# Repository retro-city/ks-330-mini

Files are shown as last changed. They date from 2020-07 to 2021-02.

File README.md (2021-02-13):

# KS-330 Mini

This project aims to provide CAD drawings and material to a faithful reproduction of one of the most iconic computer
cases from the early 1990s, the [MACASE DIAMOND
KS-330](https://web.archive.org/web/19980502082047/http://macase.com/product/personal/ks-330.htm). Ultimately the goal is to provide a set of suitable 3D Printed models to create a general purpose
miniature sized KS-330 case for a Raspberry Pi,
[MiSTer](https://github.com/MiSTer-devel/Main_MiSTer/wiki) and similar systems which will provide
compatibility with MS-DOS retro games.

Models are reproduction based on measures from an original case. The focus is primarily on visual
details. Areas which are not visible or clearly a result from practicality around the original
injection molds might not be accurately reproduced.

Please report any suggestions or issues using the GitHub issue tracker.<br />
Interested in purchasing ready-to-use products? Contact <a href="mailto:sales@retrocity.no">sales@retrocity.no</a>.

## List of manufacturers

The following manufacturers have been identified to use the KS-330 or equivalent clones or versions in their
PC production in the early 1990s:

* Executive (unoriginal case) (Italy)
* Cardinal Computer (Cookeville, TN, USA)
* TCi Computer AS (Bergen, Norway)

## Licensing

<br /><br />3D Models, CAD files and renders are licensed under the <a rel="license"
href="http://creativecommons.org/licenses/by-nc-sa/4.0/">Creative Commons
Attribution-NonCommercial-ShareAlike 4.0 International License</a>.
<br/><br/>
<a rel="license" href="https://www.gnu.org/licenses/gpl-3.0.en.html">GNU GPLv3 License</a><br />
All original programs and scripts related to this project are licensed under the <a rel="license" href="https://www.gnu.org/licenses/gpl-3.0.en.html">GNU General Public License v3</a> unless otherwise is specifically stated. 3rd party software, utilities and libaries are subject to their respective licenses.

## Components

### KS-330 Mini

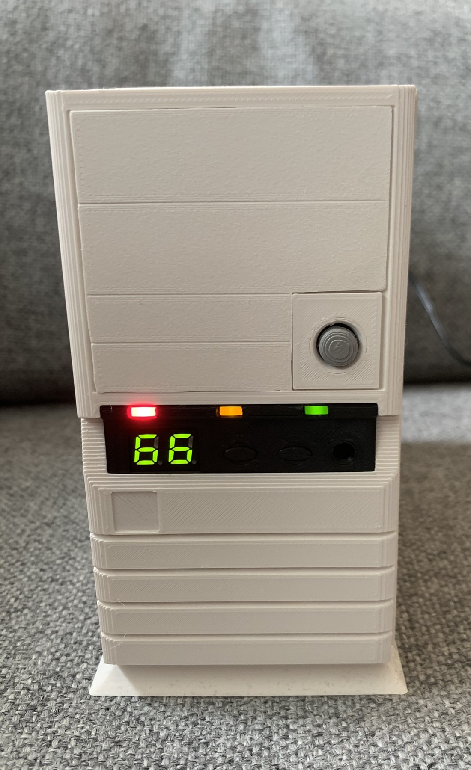
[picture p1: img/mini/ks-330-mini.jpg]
 This folder contains models speficially  adjusted for a 1:2.5 (40%) size reduction which
makes the case comparable in size to the commercially released Mini and Classic consoles. Currently there
exists a case frame with support for Rasbperry Pi SoC motherboards. Other versions are planned in
the future.

The model uses M2.5 screws in a mix of 6mm and 8mm lengths. Some holes are threaded, but should
be secured with washers and nuts where possible.

**Note!** As of `beta3` we have an increased focus on keeping the parts bacwards compatible. It is
now possible to recreate a complete case with great looks and authenticity. The IO panel is still
work in progress. General fitment/assembly will be improved in future revisions.
<br clear="right"/>
<br />

#### Front Panel

| Front | Drive-Bay-Plain | Power-Button
|---|---|---|
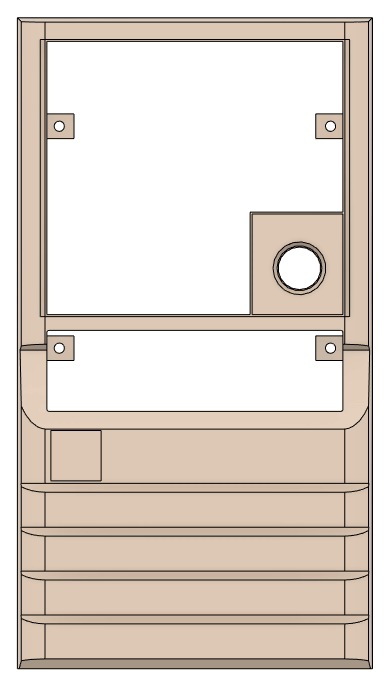
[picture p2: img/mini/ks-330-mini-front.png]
KS-330 Front
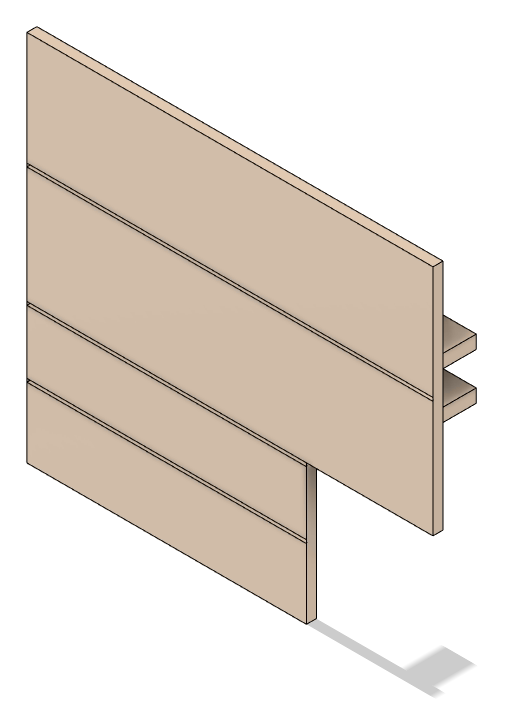
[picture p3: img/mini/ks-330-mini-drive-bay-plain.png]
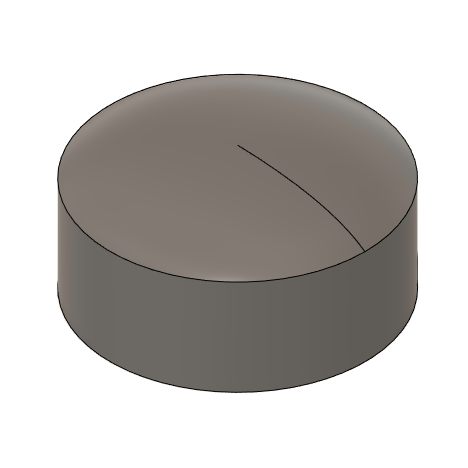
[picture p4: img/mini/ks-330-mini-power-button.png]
|   |   |   |

Front panel with hole for push button ([Judco
40-4526-00](https://www.digikey.no/product-detail/no/judco-manufacturing-inc/40-4526-00/545PB-ND/1277805))
and

**Progress:** Completed in beta3. Future revision will focus on better/more durable screw hole
positioning. Possible adjustments to IO-Panel area. More drive bay inserts will be added in the future.

#### Frame

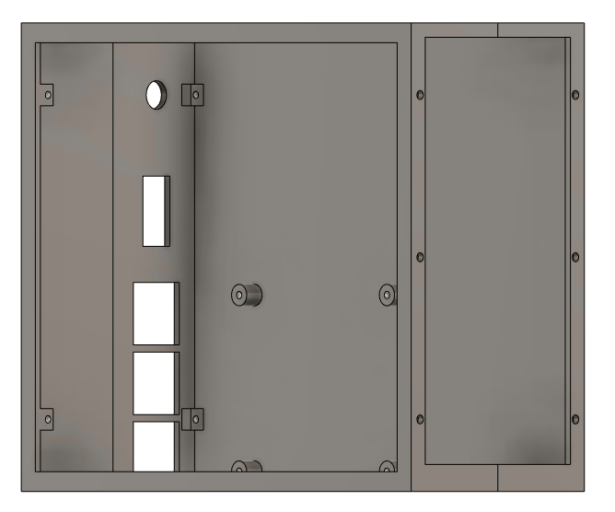
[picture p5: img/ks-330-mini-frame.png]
KS-330 Mini Frame


The inner `frame` of the case. Split into two different STLs to improve 3D printability. Screw holes
in front is intended to fasten the front panel as well as future drive bay accessory and fan
assemblies. There are screw holes in the back to fasten the `sleeve` and holes in bottom to fasten
the `base plate`. The right and the left parts can optionally be glued together.

**Progress:** Completed in beta3. Future revisions will focus on case fitment and
screw hole. Looking into using some kind of panel mount standard for IO holes.

#### Outer Sleeve

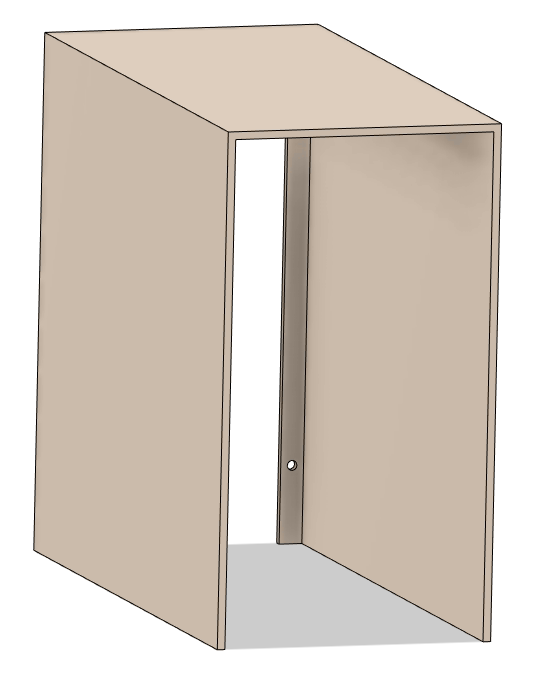
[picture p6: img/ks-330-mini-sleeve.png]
KS-330 Mini Sleeve


The outer `sleeve` is intended to go on top of the inner `frame` and align with the front panel, just as the
original case.

**Progress:** Completed in beta3. Edges on top has to be rounded in future revision.

#### IO Panel

| IO-Panel | IO-Panel-Button
|---|---|
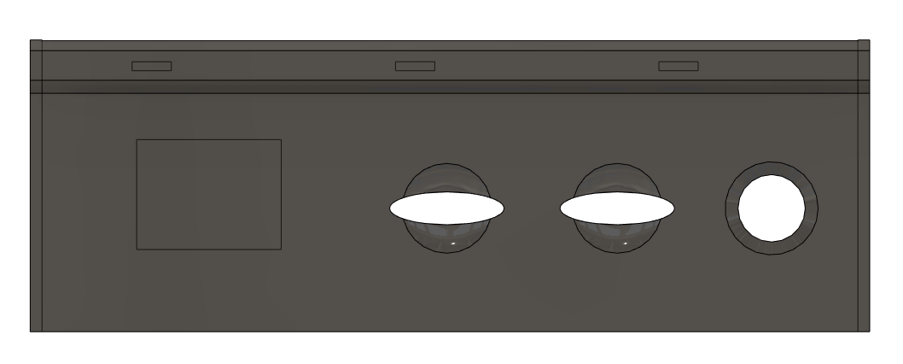
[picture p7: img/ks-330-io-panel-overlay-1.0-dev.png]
KS-330 IO Panel
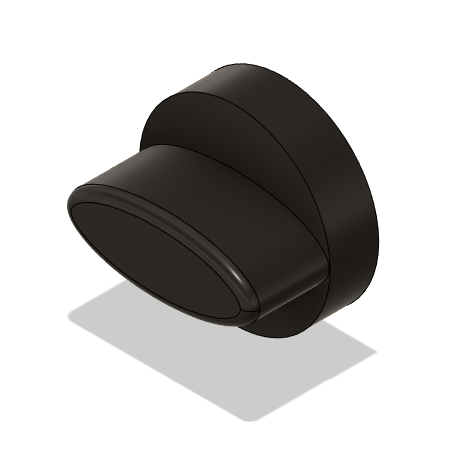
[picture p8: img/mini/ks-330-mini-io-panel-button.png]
KS-330 IO Panel
|  |  |

Customized version of the IO Panel.

LED holes are completly open to account for non-transparent
material and widened to support 2mmx5mm square LEDs. The original case uses red for HDD, yellow for
Turbo and green for Power.

The Clock Speed indicator is altered to fit [0.28" 2-digit 7-segment
displays](https://lcsc.com/product-detail/Led-Segment-Display_SUNLIGHT-SLR0282BH2C1BD-6-6_C225881.html). The
`common cathode` versions are the best as these work better with LED drivers. Green is the color
versions that closest matches the original. Our choice of LED driver fell on
MAX7219CWG+T due to a good combination of price, availability and ease of use. A poor man's option
is to just hard wire the LEDs. But then you're stuck with two identical numbers

**Progress:** Completed in beta3.

#### IO Panel PCB

| IO-Panel-PCB | | IO-Panel-PCB (early prototype) | |
|---|-|-|-|
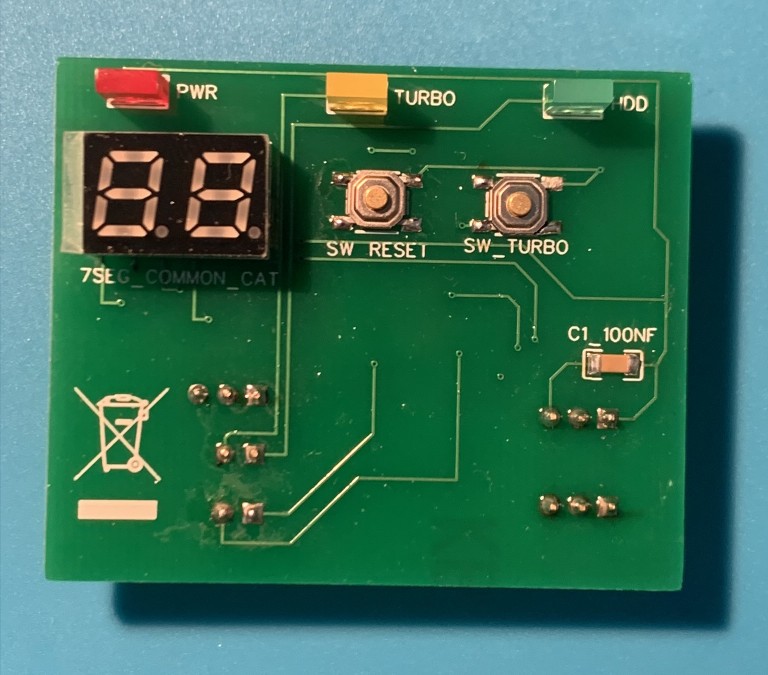
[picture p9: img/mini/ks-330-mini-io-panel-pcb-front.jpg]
KS-330 IO Panel
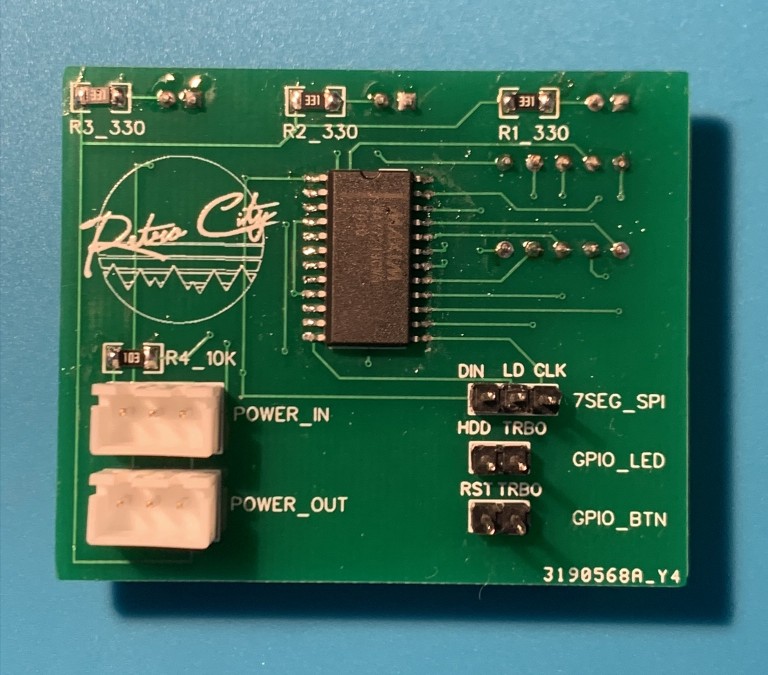
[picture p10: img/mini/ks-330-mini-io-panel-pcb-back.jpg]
KS-330 IO Panel
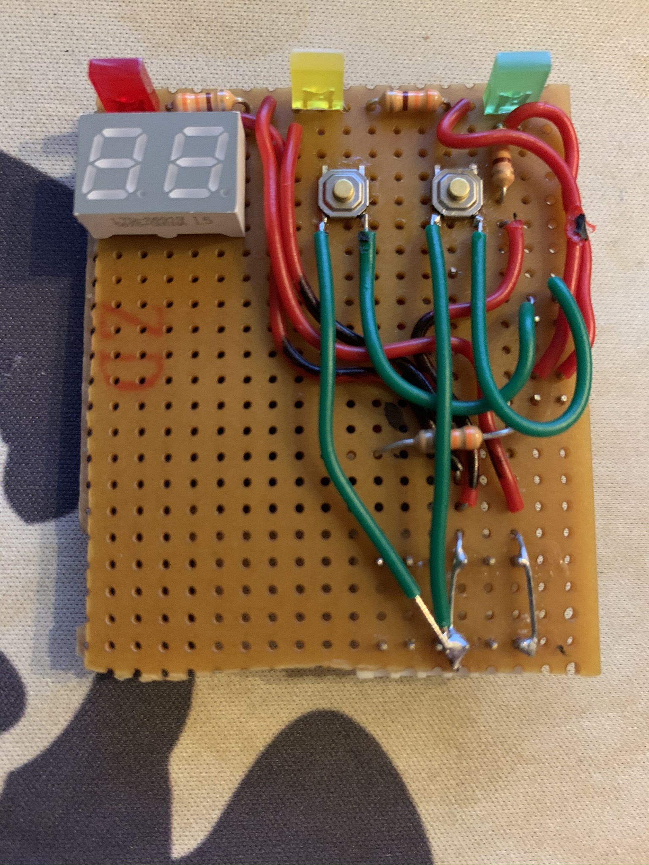
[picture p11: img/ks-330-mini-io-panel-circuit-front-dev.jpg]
KS-330 IO Panel
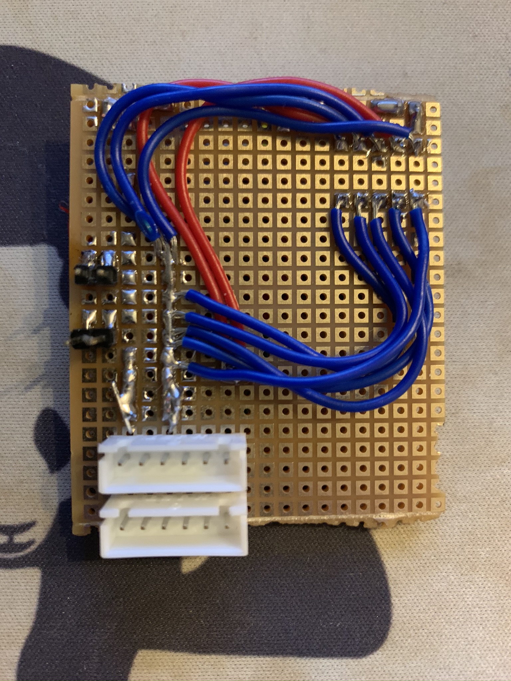
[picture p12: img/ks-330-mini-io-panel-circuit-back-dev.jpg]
KS-330 IO Panel
|  |  |  |  |

Initial revision of the PCB with Power HDD and Turbo LEDs. HDD and Turbo LEDs as well as Reset and
Turbo buttons are controlled via GPIO (buttons are wired from GPIO to Ground for the simplest
possible circuitry). 7SEG is controlled through MAX7219 controller. GPIO uses Mini-PV (Dupont) connectors. JST-XH connectors are used for 5V power in/out. 

**Progress:** Completed in beta3.

### Full Size

The components in the main STL-directory is full size replicas of the original KS-330 case. There
are minor modifications done to improve slicer stability when scaled down.

The following components have been recreated in full size.

| KS-330-Front | Full Progress |
|---|---|
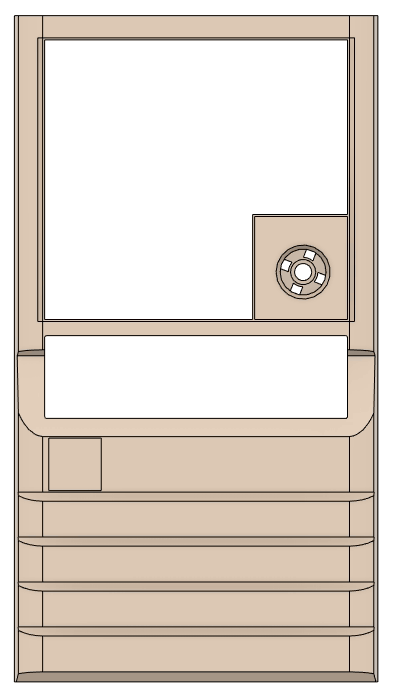
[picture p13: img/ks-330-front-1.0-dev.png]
KS-330 Front
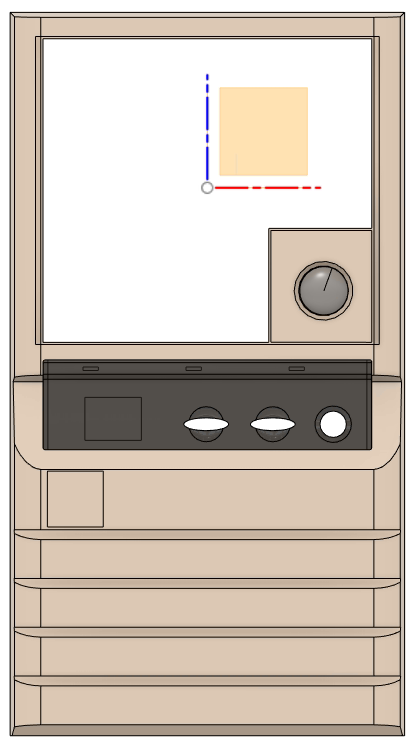
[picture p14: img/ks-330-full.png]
|   |   |

**Progress:** Work in progress, tested in 40% scale. `Front` is pretty accurate, but missing various
screw hole mounts on  the back side. Edges are not rounded.

| KS-330-IO-Panel-Overlay |
|-----------------|
| KS-330 IO Panel Overlay
|

**Progress:** Work in progress, tested in full scale. `IO-Panel-Overlay` is pretty much complete,
but missing holes to clip onto the `IO-Panel`. Edges are not rounded.

| KS-330-Base-Plate |
|-----------------|
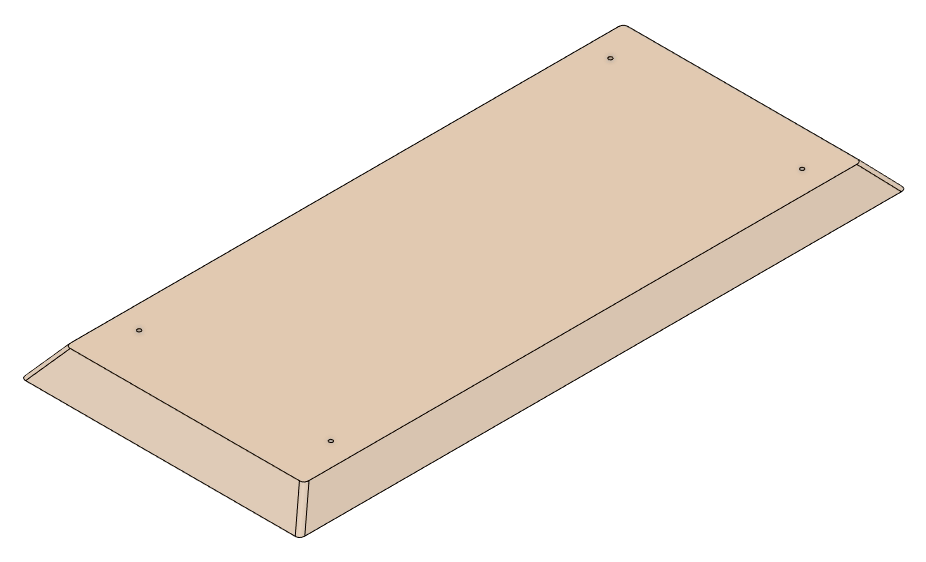
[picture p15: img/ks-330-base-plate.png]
|  |

**Progress:** Completed and tested in 40% scale. Bottom is missing arrow marking to define front.

### Clone

The clone directory contains models based on measurements from a clone system. Quality is low
compared to the original KS-330 cases and models have fitment issues also found persisted in the
original clone parts.

| Clone-Bay-Cover-3.5 | Clone-Bay-Cover-5.25 |
|---|---|
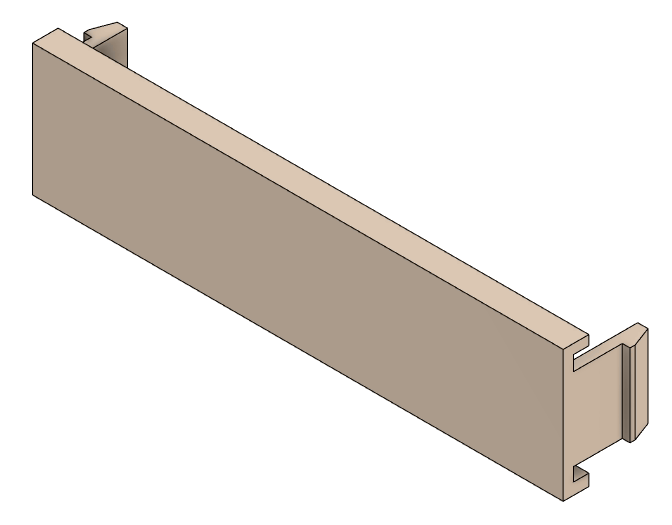
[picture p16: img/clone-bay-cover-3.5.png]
Clone Bay Cover 3.5"
|  | No picture |

Drive Bay Covers for 3.5" and 5.25" bays. Works with `KS-330-Front-Panel`. Fitment of the clone covers are
not 100%, but it is possible to adjust this with a precision knife without degrading quality. 

**Progress:** Completed, tested in full scale. 

| Clone-Power-Button |
|-----------------|
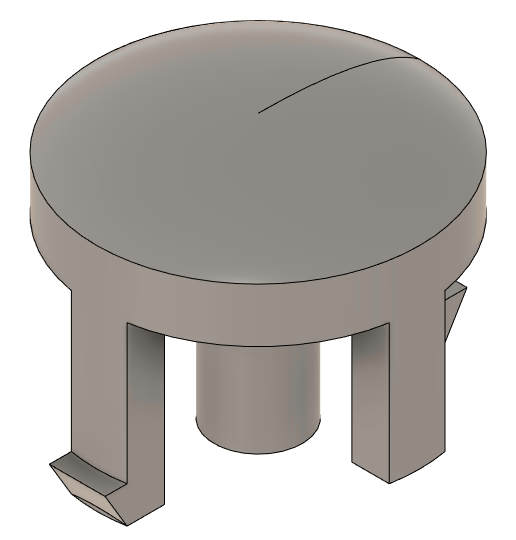
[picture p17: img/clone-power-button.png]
Clone Power Button
|  |

Power Button. Works with `KS-330-Front-Panel` but is not an accurate representation of the original
power button. Requires a low tension compression spring (Outer Ø=8mm, Inner Ø=7mm L=18mm Closed,
Squared and Ground) to work as intended.

**Progress:** Completed, tested in full scale.

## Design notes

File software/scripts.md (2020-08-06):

LED and Button Input/Output:

### Enable HDD LED:
```
sudo nano /boot/config.txt
```

Add the following `dtoverlay`
```
dtoverlay=act-led,gpio=17
```

### Turbo Button and LED:

```python
import RPi.GPIO as GPIO

# Use BCM-style pin referencing
GPIO.setmode(GPIO.BCM)

# Activate Turbo LED
GPIO.setup(27,GPIO.OUT)
GPIO.output(27,GPIO.HIGH)

# Activate Turbo Button
GPIO.setup(23, GPIO.IN, pull_up_down=GPIO.PUD_UP)

# Create a Toggle Function
def toggle_turbo(channel):
    turbo = not GPIO.input(27)
    if (turbo):
            GPIO.output(27, GPIO.HIGH)
    else:
            GPIO.output(27, GPIO.LOW)

# Add Event which runs the toggle function
GPIO.add_event_detect(23, GPIO.RISING, callback=toggle_turbo)
```

## 7 segment

https://datasheets.maximintegrated.com/en/ds/MAX7219-MAX7221.pdf
https://pypi.org/project/spidev/
https://learn.sparkfun.com/tutorials/raspberry-pi-spi-and-i2c-tutorial/all

```
 sudo apt-get install python3-pip

import time, spidev
spi = spidev.SpiDev()
spi.open(0,0)
spi.max_speed_hz = 8000000

spi.xfer2([0x0C, 0x01]) # turn on
spi.xfer2([0x09, 0x00]) # decode mode none
spi.xfer2([0x0B, 0xFF]) # set intensity

spi.xfer2([0x0F, 0x00]) # turn off displaytest
spi.xfer2([0x0F, 0x01]) # turn on displaytest

# 0x30 left digit, 0x40 right digit, 0x60 both

def init():
    spi.xfer2([0x0C, 0x01]) # turn on
    spi.xfer2([0x09, 0x00]) # decode mode none
    spi.xfer2([0x0B, 0xFF]) # set intensity
    spi.xfer2([0x0F, 0x00]) # turn off displaytest

# 66
def d66():
    spi.xfer2([0x01, 0x60])
    spi.xfer2([0x02, 0x00])
    spi.xfer2([0x03, 0x60])
    spi.xfer2([0x04, 0x60])
    spi.xfer2([0x05, 0x60])
    spi.xfer2([0x06, 0x60])
    spi.xfer2([0x07, 0x60])
    spi.xfer2([0x08, 0x00])

# 33
def d33():
    spi.xfer2([0x01, 0xFF])
    spi.xfer2([0x02, 0xFF])
    spi.xfer2([0x03, 0xFF])
    spi.xfer2([0x04, 0xFF])
    spi.xfer2([0x05, 0x00])
    spi.xfer2([0x06, 0x00])
    spi.xfer2([0x07, 0xFF])
    spi.xfer2([0x08, 0x00])

# Blank
def Blank():
    spi.xfer2([0x01, 0x00])
    spi.xfer2([0x02, 0x00])
    spi.xfer2([0x03, 0x00])
    spi.xfer2([0x04, 0x00])
    spi.xfer2([0x05, 0x00])
    spi.xfer2([0x06, 0x00])
    spi.xfer2([0x07, 0x00])
    spi.xfer2([0x08, 0x00])

# Pi
def Pi():
    spi.xfer2([0x01, 0x30])
    spi.xfer2([0x02, 0x30])
    spi.xfer2([0x03, 0x00])
    spi.xfer2([0x04, 0x00])
    spi.xfer2([0x05, 0xFF])
    spi.xfer2([0x06, 0xFF])
    spi.xfer2([0x07, 0x30])
    spi.xfer2([0x08, 0x00])

# Hi
def Hi():
    spi.xfer2([0x01, 0x00])
    spi.xfer2([0x02, 0x30])
    spi.xfer2([0x03, 0x30])
    spi.xfer2([0x04, 0x00])
    spi.xfer2([0x05, 0x60])
    spi.xfer2([0x06, 0x60])
    spi.xfer2([0x07, 0x30])
    spi.xfer2([0x08, 0x00])

# Lo
def Lo():
    spi.xfer2([0x01, 0x00])
    spi.xfer2([0x02, 0x00])
    spi.xfer2([0x03, 0x40])
    spi.xfer2([0x04, 0x60])
    spi.xfer2([0x05, 0x60])
    spi.xfer2([0x06, 0x30])
    spi.xfer2([0x07, 0x40])
    spi.xfer2([0x08, 0x00])

```

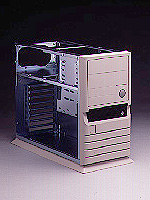
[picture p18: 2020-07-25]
img/ks-330d-i.jpg

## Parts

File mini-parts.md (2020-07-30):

Power Button:

https://www.digikey.no/product-detail/no/judco-manufacturing-inc/40-4526-00/545PB-ND/1277805
https://media.digikey.com/pdf/Data%20Sheets/Judco%20PDFs/40-4526-00.pdf

Power Jack:

https://www.digikey.no/product-detail/no/mpd-memory-protection-devices/EJ501A/EJ501A-ND/2439531

LEDS:

https://www.digikey.no/product-detail/no/kingbright/WP113IDT/754-1201-ND/1747600
https://www.digikey.no/product-detail/no/kingbright/WP113GDT/754-1200-ND/1747599
https://www.digikey.no/product-detail/no/kingbright/WP113YDT/754-1203-ND/1747602

Turbo Switch:

https://www.digikey.no/product-detail/no/e-switch/TL2230EEF100/EG6030-ND/3778181

Reset Switch:

(note: silent, not good enough sound)
https://www.digikey.no/product-detail/no/e-switch/TL2230OAF140/EG6032-ND/4029360

Need to find lower height switches if they are to fit PCB.

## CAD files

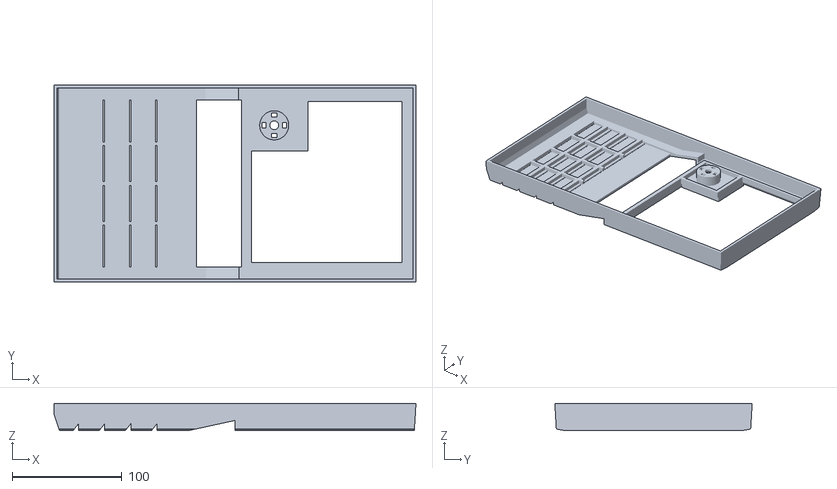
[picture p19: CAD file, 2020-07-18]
stl/clone/front.stl
330.0 x 180.0 x 25.0

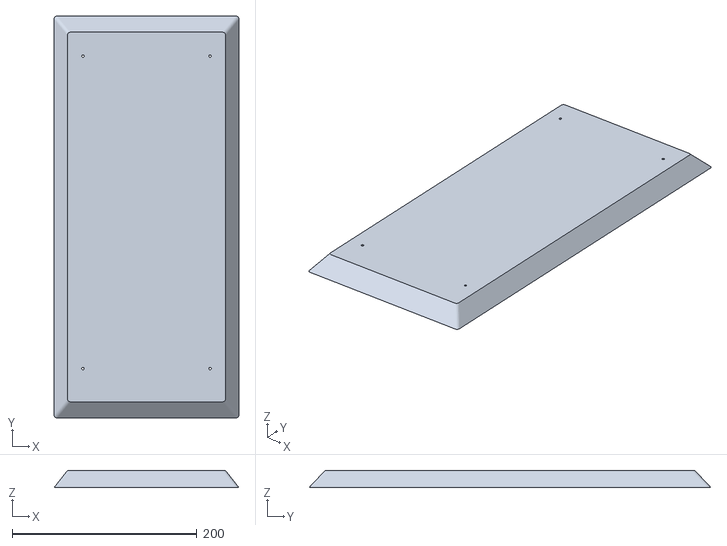
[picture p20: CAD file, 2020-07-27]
stl/full/ks-330-base-plate.stl
200.0 x 435.0 x 18.5

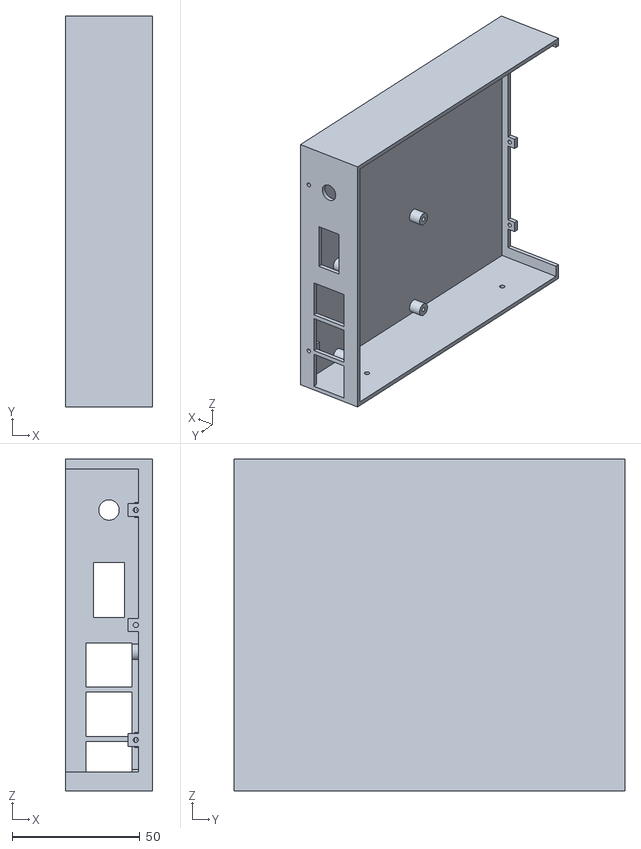
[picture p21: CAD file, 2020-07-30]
stl/mini/1.0-beta2/ks-330-mini-frame-right-rpi-1.0-beta2.stl
34.0 x 153.0 x 130.0

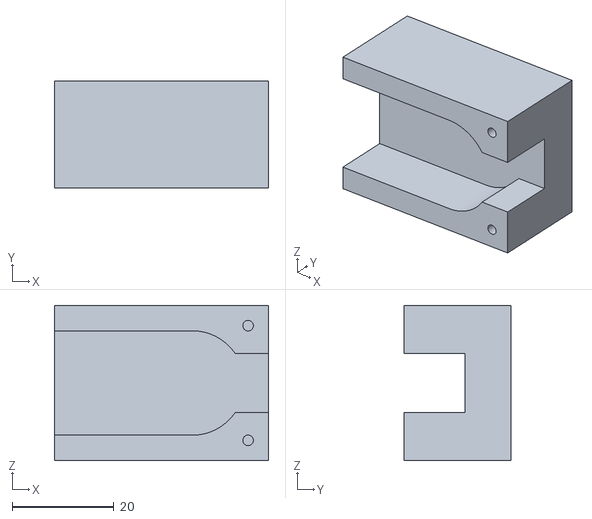
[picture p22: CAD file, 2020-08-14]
stl/mini/1.0-beta3/ks-330-mini-hdmi-mount-1.0-beta3.stl
42.0 x 21.0 x 30.5

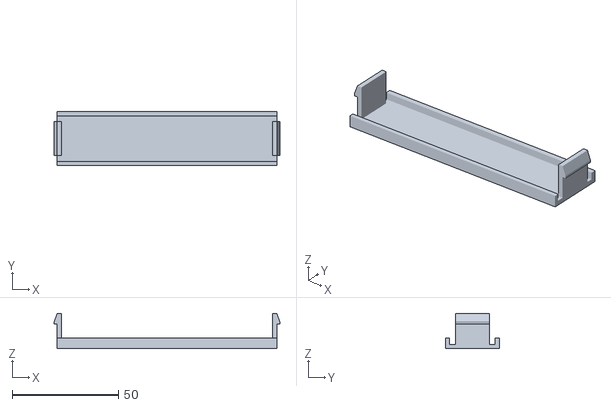
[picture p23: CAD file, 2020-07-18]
stl/clone/cover-3.5.stl
106.2 x 25.6 x 16.5

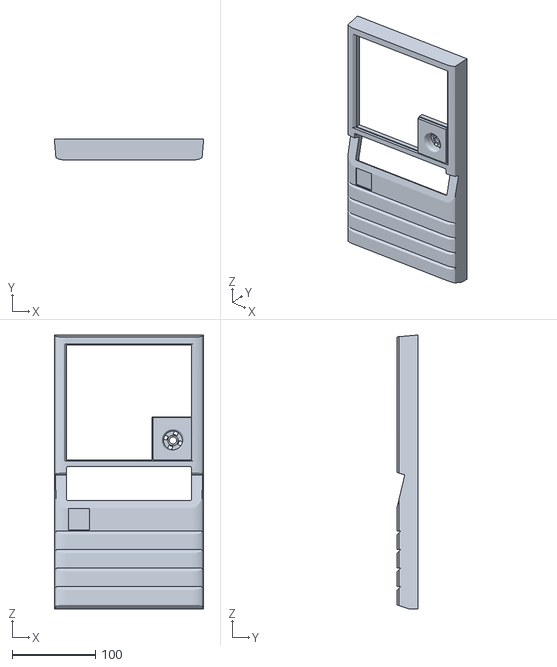
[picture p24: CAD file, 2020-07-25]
stl/full/ks-330-front-1.0-dev3.stl
180.0 x 25.5 x 330.0

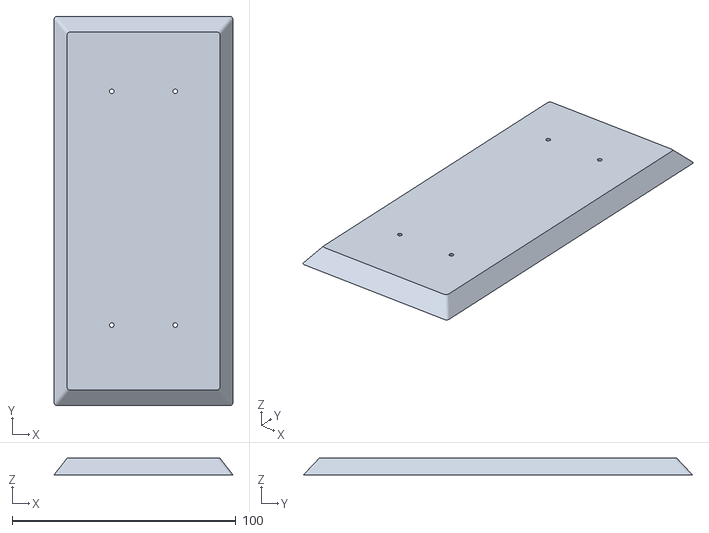
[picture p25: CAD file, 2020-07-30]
stl/mini/1.0-beta2/ks-330-mini-base-plate-1.0-beta2.stl
80.0 x 174.0 x 7.40

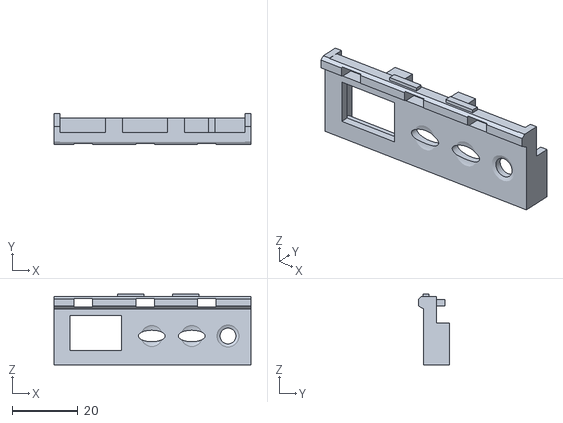
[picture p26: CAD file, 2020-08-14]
stl/mini/1.0-beta3/ks-330-mini-io-panel-1.0-beta3.stl
59.9 x 9.44 x 21.5

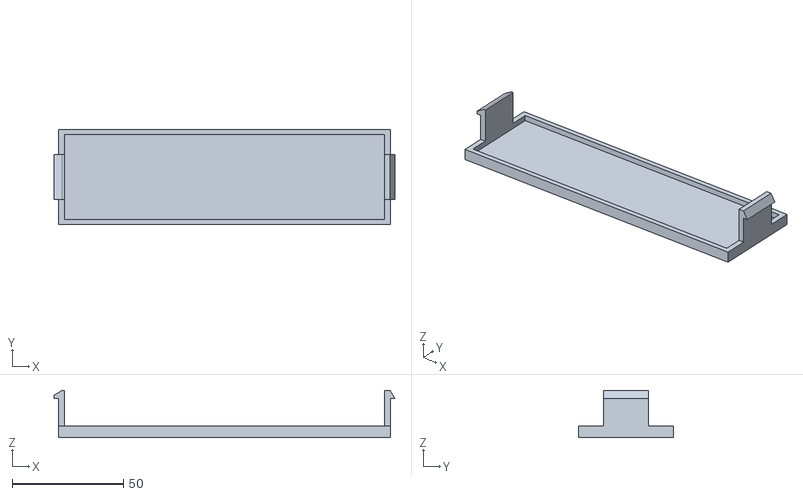
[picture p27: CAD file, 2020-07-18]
stl/clone/cover-5.25.stl
153.1 x 42.8 x 21.2

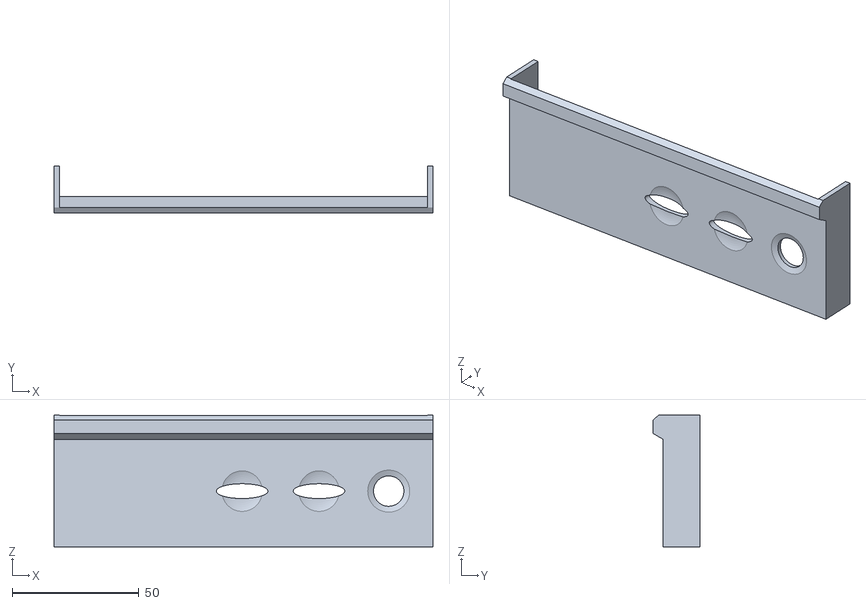
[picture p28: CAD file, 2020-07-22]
stl/full/ks-330-io-panel-overlay-1.0-dev.stl
149.8 x 18.6 x 52.0

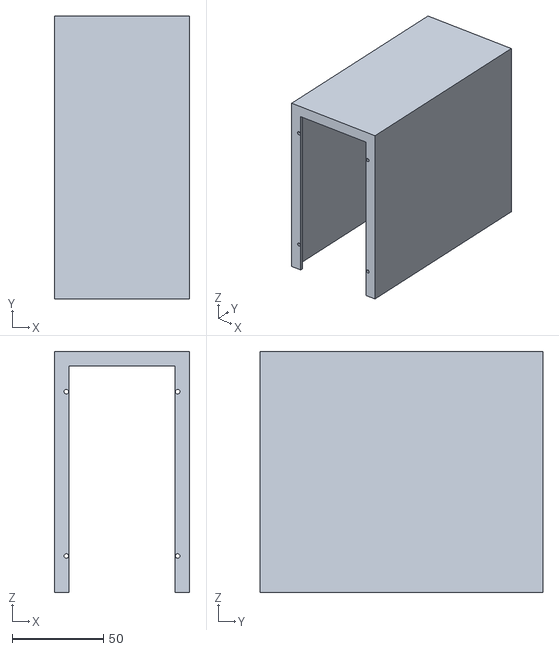
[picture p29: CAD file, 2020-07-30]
stl/mini/1.0-beta2/ks-330-mini-sleeve-1.0-beta2.stl
74.0 x 155.0 x 132.0

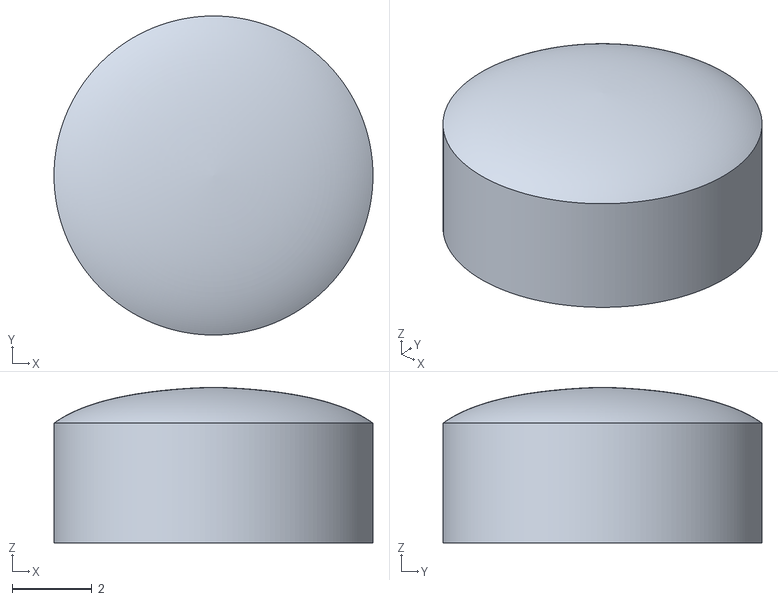
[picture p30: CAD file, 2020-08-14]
stl/mini/1.0-beta3/ks-330-mini-power-button-1.0-beta3.stl
8.00 x 8.00 x 3.90

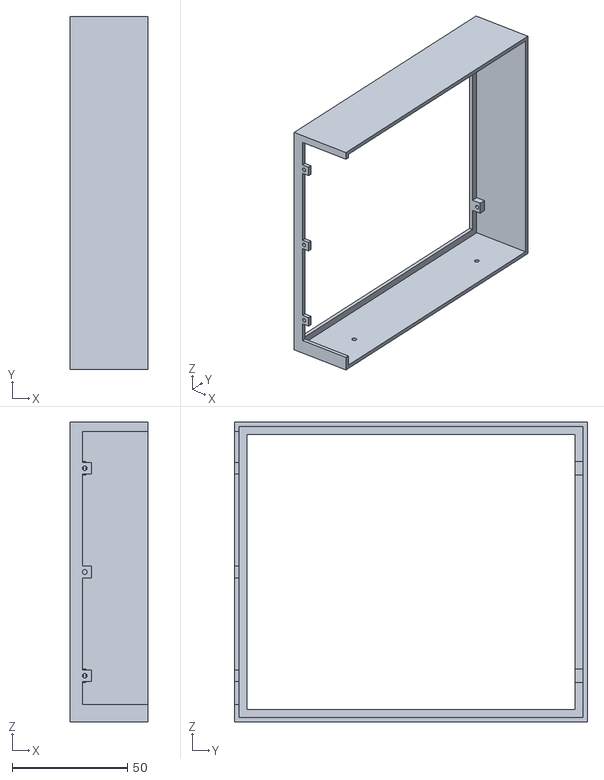
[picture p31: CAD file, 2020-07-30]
stl/mini/1.0-beta2/ks-330-mini-frame-left-1.0-beta2.stl
34.0 x 153.0 x 130.0

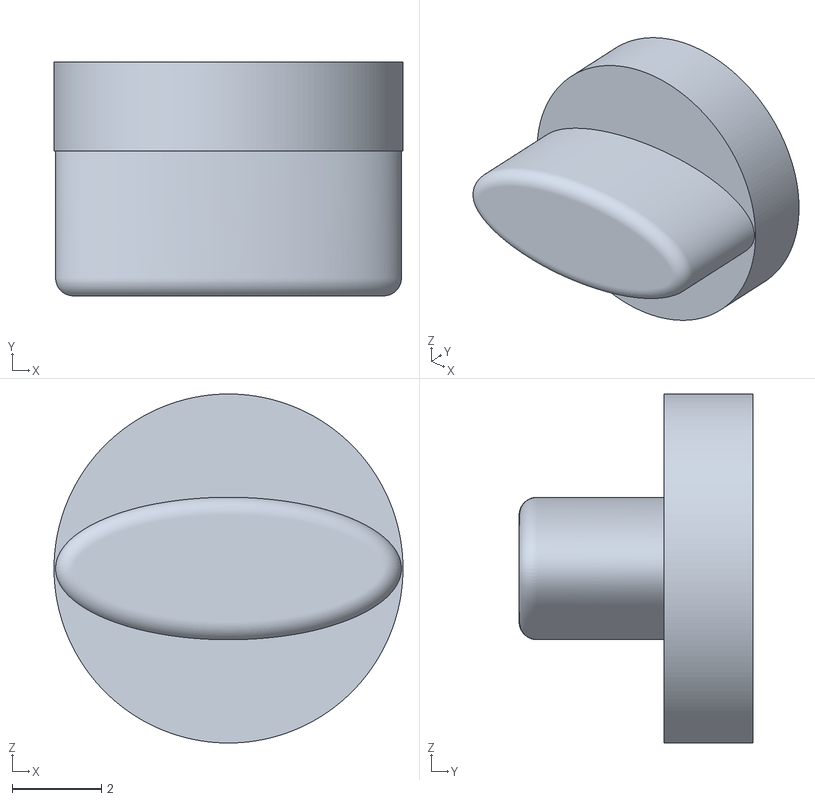
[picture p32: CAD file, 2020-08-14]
stl/mini/1.0-beta3/ks-330-mini-io-panel-button-1.0-beta3.stl
7.84 x 5.25 x 7.84

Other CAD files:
stl/full/ks-330-front-1.0-dev2.stl
stl/full/ks-330-front-1.0-dev.stl
stl/mini/1.0-beta2/ks-330-mini-front-1.0-beta2.stl
stl/mini/1.0-beta3/ks-330-mini-frame-right-rpi-1.0-beta3.stl
f3d/clone/clone-bay-cover-3.5.f3d
f3d/clone/clone-bay-cover-5.25.f3d
f3d/clone/clone-power-button.f3d
f3d/clone/front.f3d
f3d/full/ks-330-front-1.0-dev.f3d
f3d/full/ks-330-front-1.0-dev2.f3d
f3d/full/ks-330-io-panel-overlay-1.0-dev.f3d
stl/mini/1.0-beta2/ks-330-mini-io-panel-1.0-beta2.stl
stl/mini/1.0-beta3/ks-330-mini-base-plate-1.0-beta3.stl
stl/mini/1.0-beta3/ks-330-mini-drive-bay-plain-1.0-beta3.stl
stl/mini/1.0-beta3/ks-330-mini-frame-left-1.0-beta3.stl
stl/mini/1.0-beta3/ks-330-mini-front-1.0-beta3.stl
stl/mini/1.0-beta3/ks-330-mini-sleeve-1.0-beta3.stl

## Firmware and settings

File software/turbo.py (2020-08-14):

#!/usr/bin/python
import os, time, spidev
import RPi.GPIO as GPIO
spi = spidev.SpiDev()

# Create a Toggle Function
def toggle_turbo(channel):
    turbo = not GPIO.input(27)
    if (turbo):
            GPIO.output(27, GPIO.HIGH)
            d66()
    else:
            GPIO.output(27, GPIO.LOW)
            d33()

def toggle_reset(channel):
    print("reset pressed")
    os.system("killall dosbox")

def d66():
    spi.xfer2([0x01, 0b01011111])
    spi.xfer2([0x02, 0b01011111])

def d33():
    spi.xfer2([0x01, 0b01111001])
    spi.xfer2([0x02, 0b01111001])

def dhi():
    spi.xfer2([0x01, 0b00000110])
    spi.xfer2([0x02, 0b00110111])

def dlo():
    spi.xfer2([0x01, 0b00011101])
    spi.xfer2([0x02, 0b00001110])

def drc():
    spi.xfer2([0x01, 0b01001110])
    spi.xfer2([0x02, 0b00000101])

def dpi():
    spi.xfer2([0x01, 0b00000110])
    spi.xfer2([0x02, 0b01100111])

if __name__ == "__main__":
    # Init GPIO
    GPIO.setmode(GPIO.BCM)
    GPIO.setup(27,GPIO.OUT)
    GPIO.output(27,GPIO.HIGH)
    GPIO.setup(23, GPIO.IN, pull_up_down=GPIO.PUD_UP) # Turbo
    GPIO.setup(24, GPIO.IN, pull_up_down=GPIO.PUD_UP) # Reset

    # Init 7SEG
    spi.open(0,0)
    spi.max_speed_hz = 8000000
    spi.xfer2([0x0C, 0x01]) # turn on
    spi.xfer2([0x09, 0x00]) # decode mode none
    spi.xfer2([0x0B, 0x11]) # set intensity
    spi.xfer2([0x0F, 0x00]) # turn off displaytest
    d66()

    # Add events
    GPIO.add_event_detect(23, GPIO.RISING, callback=toggle_turbo)
    GPIO.add_event_detect(24, GPIO.RISING, callback=toggle_reset)

    try:
        while True:
            time.sleep(10)
    except KeyboardInterrupt:
        GPIO.cleanup()

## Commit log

2020-07-18 Initial version. Front only
    [front.f3d, front.stl]
2020-07-18 Added STL for drive bay covers
    [cover-3.5.stl, cover-5.25.stl]
2020-07-18 Added Power Button STL
2020-07-18 Better rounding of power button
2020-07-18 Added fusion 360 archives for cover and pwr btn
    [cover-3.5.f3d, cover-5.25.f3d, power-button.f3d]
2020-07-18 front improvements. pwrbtn fitment improvement
    [front.f3d, front.stl, power-button.f3d]
2020-07-19 Restructured. Updated README.md
    [cover-3.5.f3d, cover-3.5.stl, cover-5.25.f3d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]
2020-07-21 dev version 1 based on original case
    [ks-330-front-1.0-dev.f3d, ks-330-front_1.0-dev.stl]
2020-07-22 Added dev2 version with improved accuracy + fixes for smaller scale
    [ks-330-front-1.0-dev.stl, ks-330-front-1.0-dev2.f3d, ks-330-front-1.0-dev2.stl]
2020-07-22 Added io-panel-overlay dev version
    [ks-330-io-panel-overlay-1.0-dev.f3d, ks-330-io-panel-overlay-1.0-dev.stl]
2020-07-25 dev3 with various thickness fixes for 40% 3d print
    [ks-330-front-1.0-dev3.stl]
2020-07-27 Various totally untuned mini models.
    [ks-330-base-plate.stl, ks-330-mini-internal-1.0-dev.stl, ks-330-mini-io-panel-overlay-1.0-dev.stl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]
2020-07-27 Added internal frames. Motherboard screw holes for RPi
    [ks-330-mini-frame-left-1.0-dev.stl, ks-330-mini-frame-right-rpi-1.0-dev.stl, ks-330-mini-internal-1.0-dev.stl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]
2020-07-28 screwhole and aligment bugfixes
    [ks-330-mini-frame-left-1.0-dev.stl, ks-330-mini-frame-right-rpi-1.0-dev.stl]
2020-07-28 Naming and readme improvements
    [clone-bay-cover-3.5.f3d, clone-bay-cover-5.25.f3d, clone-power-button.f3d]
2020-07-30 Front panel in beta. Working on IO panel component fitment
    [ks-330-mini-front-panel-1.0-beta1.stl, ks-330-mini-io-panel-1.0-dev.stl, ks-330-mini-io-panel-1.0-dev3.stl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]
2020-07-30 Mini Beta 2 - renamed all to avoid confiusion
    [ks-330-mini-base-plate-1.0-beta1.stl, ks-330-mini-frame-left-1.0-beta1.stl, ks-330-mini-frame-left-1.0-dev.stl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]
2020-07-31 moved full files into subfolders to avoid confusion
    [ks-330-base-plate.stl, ks-330-front-1.0-dev.f3d, ks-330-front-1.0-dev.stl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]
2020-08-02 Adding first part of beta3 components
    [ks-330-mini-base-plate-1.0-beta2.stl, ks-330-mini-base-plate-1.0-beta3.stl, ks-330-mini-drive-bay-plain-1.0-beta3.stl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]
2020-08-06 Corrections to beta3 revision
    [ks-330-mini-drive-bay-plain-1.0-beta3.stl, ks-330-mini-frame-left-1.0-beta3.stl, ks-330-mini-frame-right-rpi-1.0-beta3.stl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]
2020-08-14 Beta3 finished
    [ks-330-mini-hdmi-mount-1.0-beta3.stl, ks-330-mini-io-panel-1.0-beta3.stl, ks-330-mini-io-panel-button-1.0-beta3.stl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]
